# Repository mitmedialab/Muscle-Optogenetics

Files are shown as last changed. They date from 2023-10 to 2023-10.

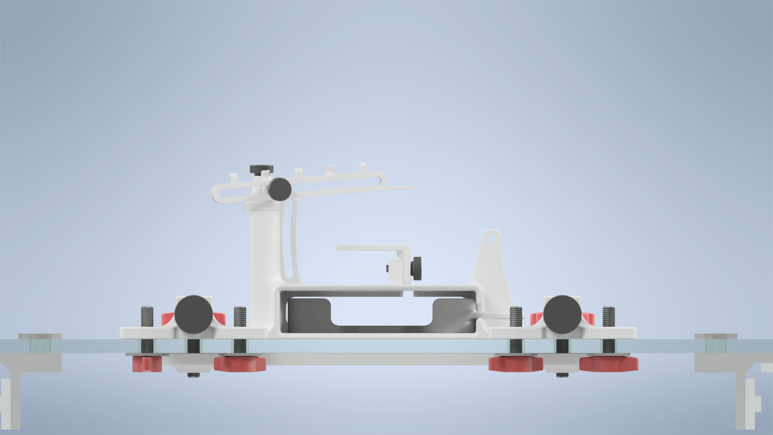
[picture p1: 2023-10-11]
Muscle Characterization Apparatus/Renders/Rendering IV.png

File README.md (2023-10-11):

# Muscle-Optogenetics

Muscle characterization apparatus and closed-loop control files for the paper: Closed-loop optogenetic neuromodulation enables high-fidelity fatigue-resistant muscle control



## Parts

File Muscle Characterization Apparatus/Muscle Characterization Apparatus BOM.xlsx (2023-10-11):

Muscle Characterization Platform Bill of Materials
Description | Use | Part no. | Supplier | Quantity | Cost | Total Cost | Notes
Stainless Steel M5 Nuts (pack of 100) | Nuts for trim adjustment hardware | 91828A241 | Mcmaster Carr (https://www.mcmaster.com/91828A241) | 1 | $5.55 | $5.55 | Just need 10 for assembly
Stainless Steel M3 Nuts (pack of 100) | Nuts for leg shelf | 91828A211 | Mcmaster Carr (https://www.mcmaster.com/91828A211) | 1 | $5.55 | $5.55 | Just need 3 for assembly
Stainless Steel 1/4"-20 Hex Nuts (pack of 50) | Nuts to bolt T-slot sliders | 92673A113 | Mcmaster Carr (https://www.mcmaster.com/92673A113) | 1 | $2.27 | $2.27 | Just need 8 for assembly
Stainless Steel M5 Fender Washers (pack of 100) | Washers to accommodate for M5 hole tolerances | 90313A103 | Mcmaster Carr (https://www.mcmaster.com/90313A103) | 1 | $5.96 | $5.96 | Just need 4 for assembly
Stainless Steel 1/4" Fender Washers (pack of 25) | Washers to accommodate for 1/4"-20 hole tolerances | 91525A415 | Mcmaster Carr (https://www.mcmaster.com/91525A415) | 1 | $8.80 | $8.80 | Just need 8 for assembly
Stainless Steel 1/4"-20 x 1" Screws (pack of 10) | Screws to bolt T-slot sliders | 92185A42 | Mcmaster Carr (https://www.mcmaster.com/92185A542) | 1 | $3.44 | $3.44 | Need 8 for assembly
Stainless Steel M5x35mm Screws (pack of 25) | Screws for trim hardware | 91292A193 | Mcmaster Carr (https://www.mcmaster.com/91292A193) | 1 | $6.07 | $6.07 | Just need 2 for assembly
Stainless Steel M5x20mm Screws (pack of 50) | Screws to clamp printed parts | 90348A022 | Mcmaster Carr (https://www.mcmaster.com/90348A022) | 1 | $9.91 | $9.91 | Need 8 for assembly
Plastic M3x10mm Thumb Screws (pack of 10) | Thumbscrew for leg shelf | 96016A553 | Mcmaster Carr (https://www.mcmaster.com/96016A553) | 1 | $5.25 | $5.25 | Just need 1
Plastic M3x20mm Thumb Screws (pack of 10) | Thumbscrews for LED Arm | 96016A556 | Mcmaster Carr (https://www.mcmaster.com/96016A556) | 1 | $5.50 | $5.50 | Just need 2
Compression Springs (pack of 5) | Springs to preload trim adjustment | 9434K58 | Mcmaster Carr (https://www.mcmaster.com/9434K58) | 1 | $4.98 | $4.98 | Just need 2 for assembly
T-Slot Frame Sliders | Sliders to adjust fixture location on T-slot frames | 47065T959 | Mcmaster Carr (https://www.mcmaster.com/47065T959) | 2 | $46.16 | $92.32 | Should have these on hand
Round M5 Thumbscrew Heads (pack of 50) | Caps to allow hand adjustments for M5 screws | 91175A063 | Mcmaster Carr (https://www.mcmaster.com/91175A063) | 1 | $10.20 | $10.20 | Just need 2--install on 35mm M5 bolts
Two Arm M5 Thumbscrew Heads (pack of 50) | Caps to allow hand adjustments for M5 screws | 91175A081 | Mcmaster Carr (https://www.mcmaster.com/91175A081) | 1 | $8.44 | $8.44 | Need 8--install on 20mm M5 bolts
Polycarbonate Baseplate | Baseplate for the fixture | W91-03630 | Curbell Plastics (https://www.curbellplastics.com/Shop-Materials/Product/Clearance-Polycarbonate-Sheet/W91-03630/Clearance-Polycarbonate-Sheet-Clear-(0-220-in-x-12-in-x-72-in)-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) | 1 | $26.50 | $26.50 | Need to cut this down to 12" by 16.5"
Stainless steel socket head M2.5 x 0.45 mm screw, 10 mm | Screw for lever transducer | 91292A014 | Mcmaster Carr (https://www.mcmaster.com/catalog/126/3304) | 1 | $5.42 | $5.42 | Just need 1
Stainless steel socket head M2.6 x 0.45 mm screw, 10 mm | Screw for lever transducer | 91292A342 | Mcmaster Carr (https://www.mcmaster.com/catalog/126/3304) | 1 | $8.58 | $8.58 | Just need 1
3D Printed Parts
Name | Use | Quantity
Long Bottom Nut Traps | Hold M5 Nuts in place for clamp hardware | 2
Fixture Pull Bracket | Trim tension bracket | 2
reviii Fixture Body | Mouse fixture | 1
Leg Shelf | Platform for mouse leg | 1
Heatpad Tray | Tray for heatpad to warm mouse | 1
LED Arm | Arm to hold UV LED | 1
LED Elbow | Joint between LED Arm and Fixture base | 1
LED Washer | Slot Washer for LED Arm | 1

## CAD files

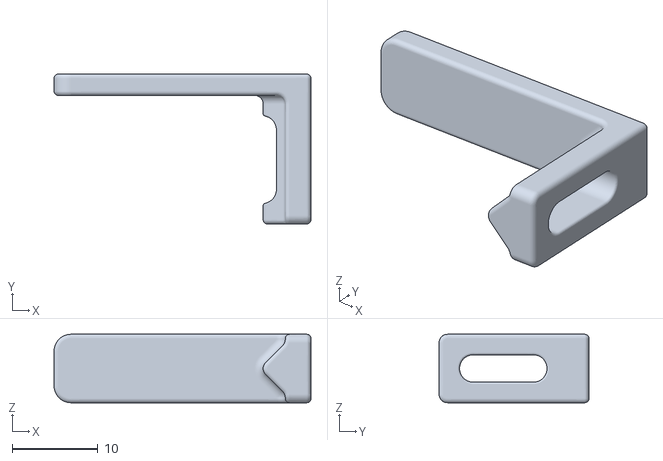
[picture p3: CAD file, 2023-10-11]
Muscle Characterization Apparatus/STLs for 3D printed parts/Leg Shelf.stl
30.0 x 17.5 x 8.00

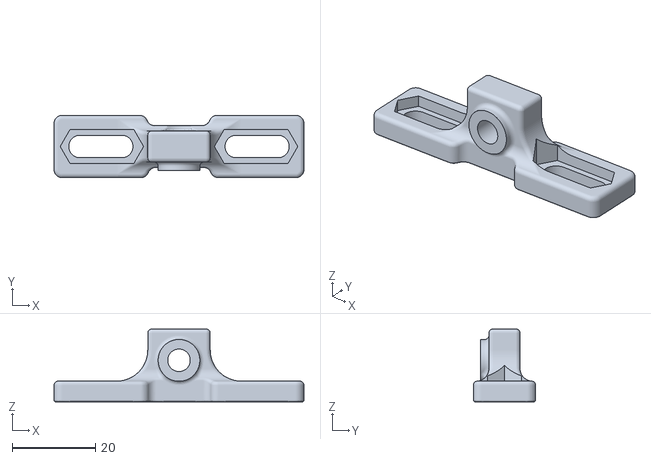
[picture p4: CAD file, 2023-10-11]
Muscle Characterization Apparatus/STLs for 3D printed parts/Fixture Pull Bracket.stl
60.0 x 15.0 x 17.5

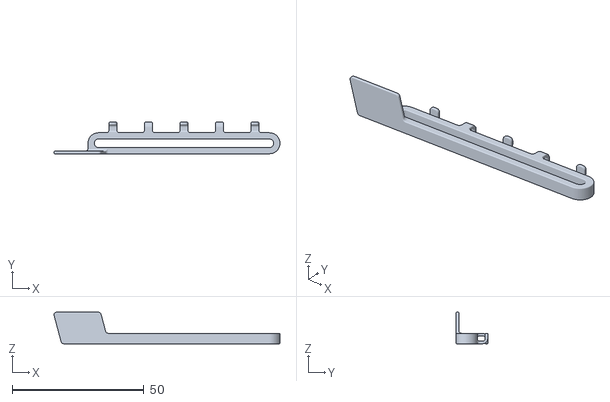
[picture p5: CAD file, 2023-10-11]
Muscle Characterization Apparatus/STLs for 3D printed parts/LED Arm.stl
85.9 x 12.0 x 12.0

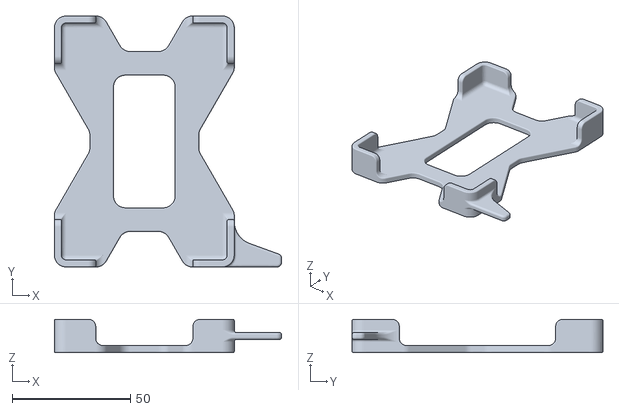
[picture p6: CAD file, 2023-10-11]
Muscle Characterization Apparatus/STLs for 3D printed parts/Heatpad Tray.stl
96.0 x 106.0 x 14.0

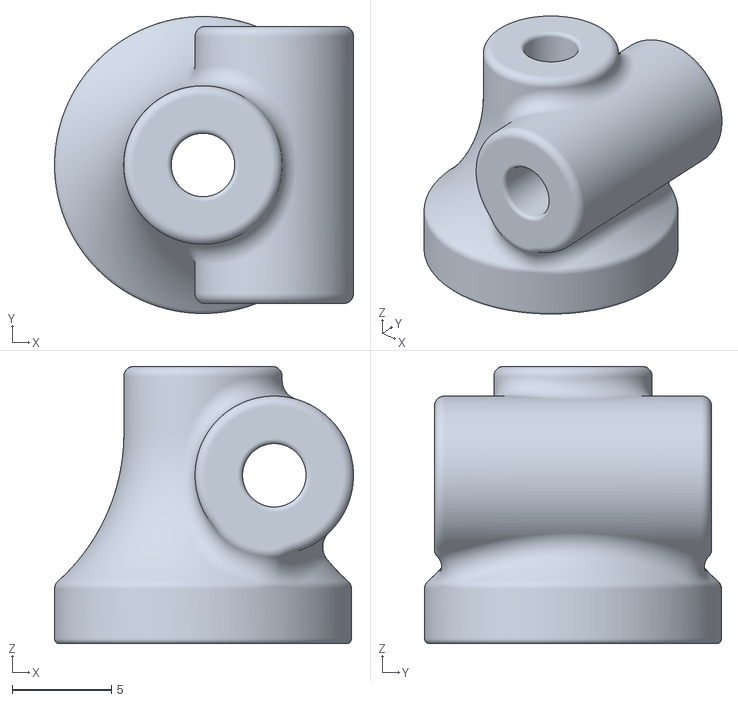
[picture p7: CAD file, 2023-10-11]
Muscle Characterization Apparatus/STLs for 3D printed parts/LED Elbow.stl
15.1 x 15.0 x 14.0

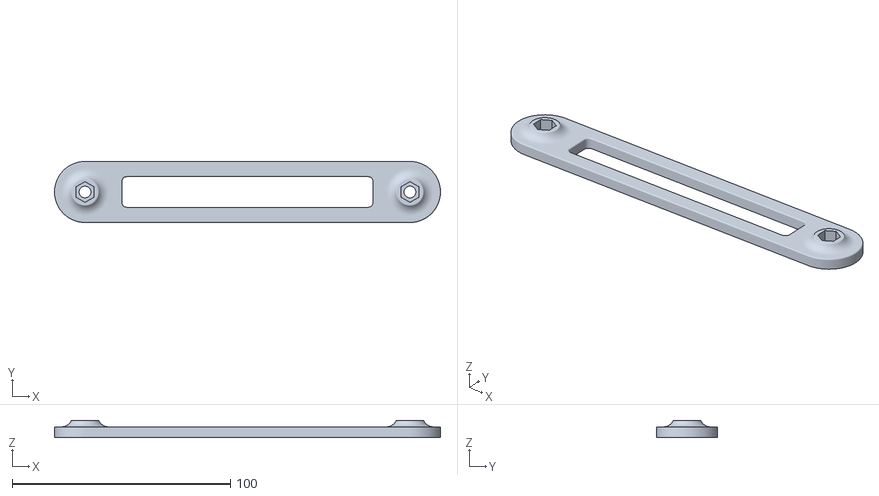
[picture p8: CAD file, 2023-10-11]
Muscle Characterization Apparatus/STLs for 3D printed parts/Long Bottom Nut Traps.stl
177.0 x 28.0 x 8.00

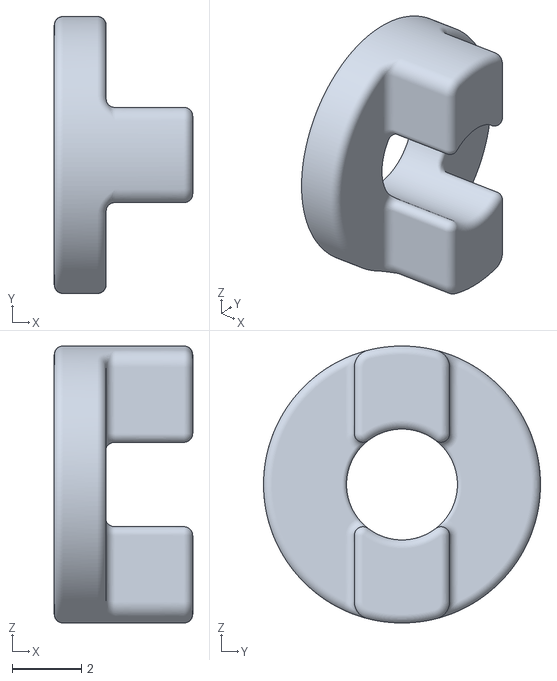
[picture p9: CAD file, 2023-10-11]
Muscle Characterization Apparatus/STLs for 3D printed parts/LED Washer.stl
4.00 x 8.00 x 8.00

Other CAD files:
Muscle Characterization Apparatus/Inventor Files - rev ix/47065T959_ALUMINUM T-SLOTTED FRAMING EXTRUSION.ipt
Muscle Characterization Apparatus/Inventor Files - rev ix/90313A103_18-8 STAINLESS STEEL OVERSIZED WASHER.ipt
Muscle Characterization Apparatus/Inventor Files - rev ix/91525A415_TYPE 316 STAINLESS STEEL FLAT WASHER.ipt
Muscle Characterization Apparatus/Inventor Files - rev ix/9434K580_MUSIC-WIRE STEEL COMPRESSION SPRINGS.ipt
Muscle Characterization Apparatus/Inventor Files - rev ix/Base Plate.ipt
Muscle Characterization Apparatus/Inventor Files - rev ix/Fixture Pull Bracket.ipt
Muscle Characterization Apparatus/Inventor Files - rev ix/Heatpad Tray.ipt
Muscle Characterization Apparatus/Inventor Files - rev ix/LED Arm.ipt
Muscle Characterization Apparatus/Inventor Files - rev ix/LED Elbow.ipt
Muscle Characterization Apparatus/Inventor Files - rev ix/LED Washer.ipt
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

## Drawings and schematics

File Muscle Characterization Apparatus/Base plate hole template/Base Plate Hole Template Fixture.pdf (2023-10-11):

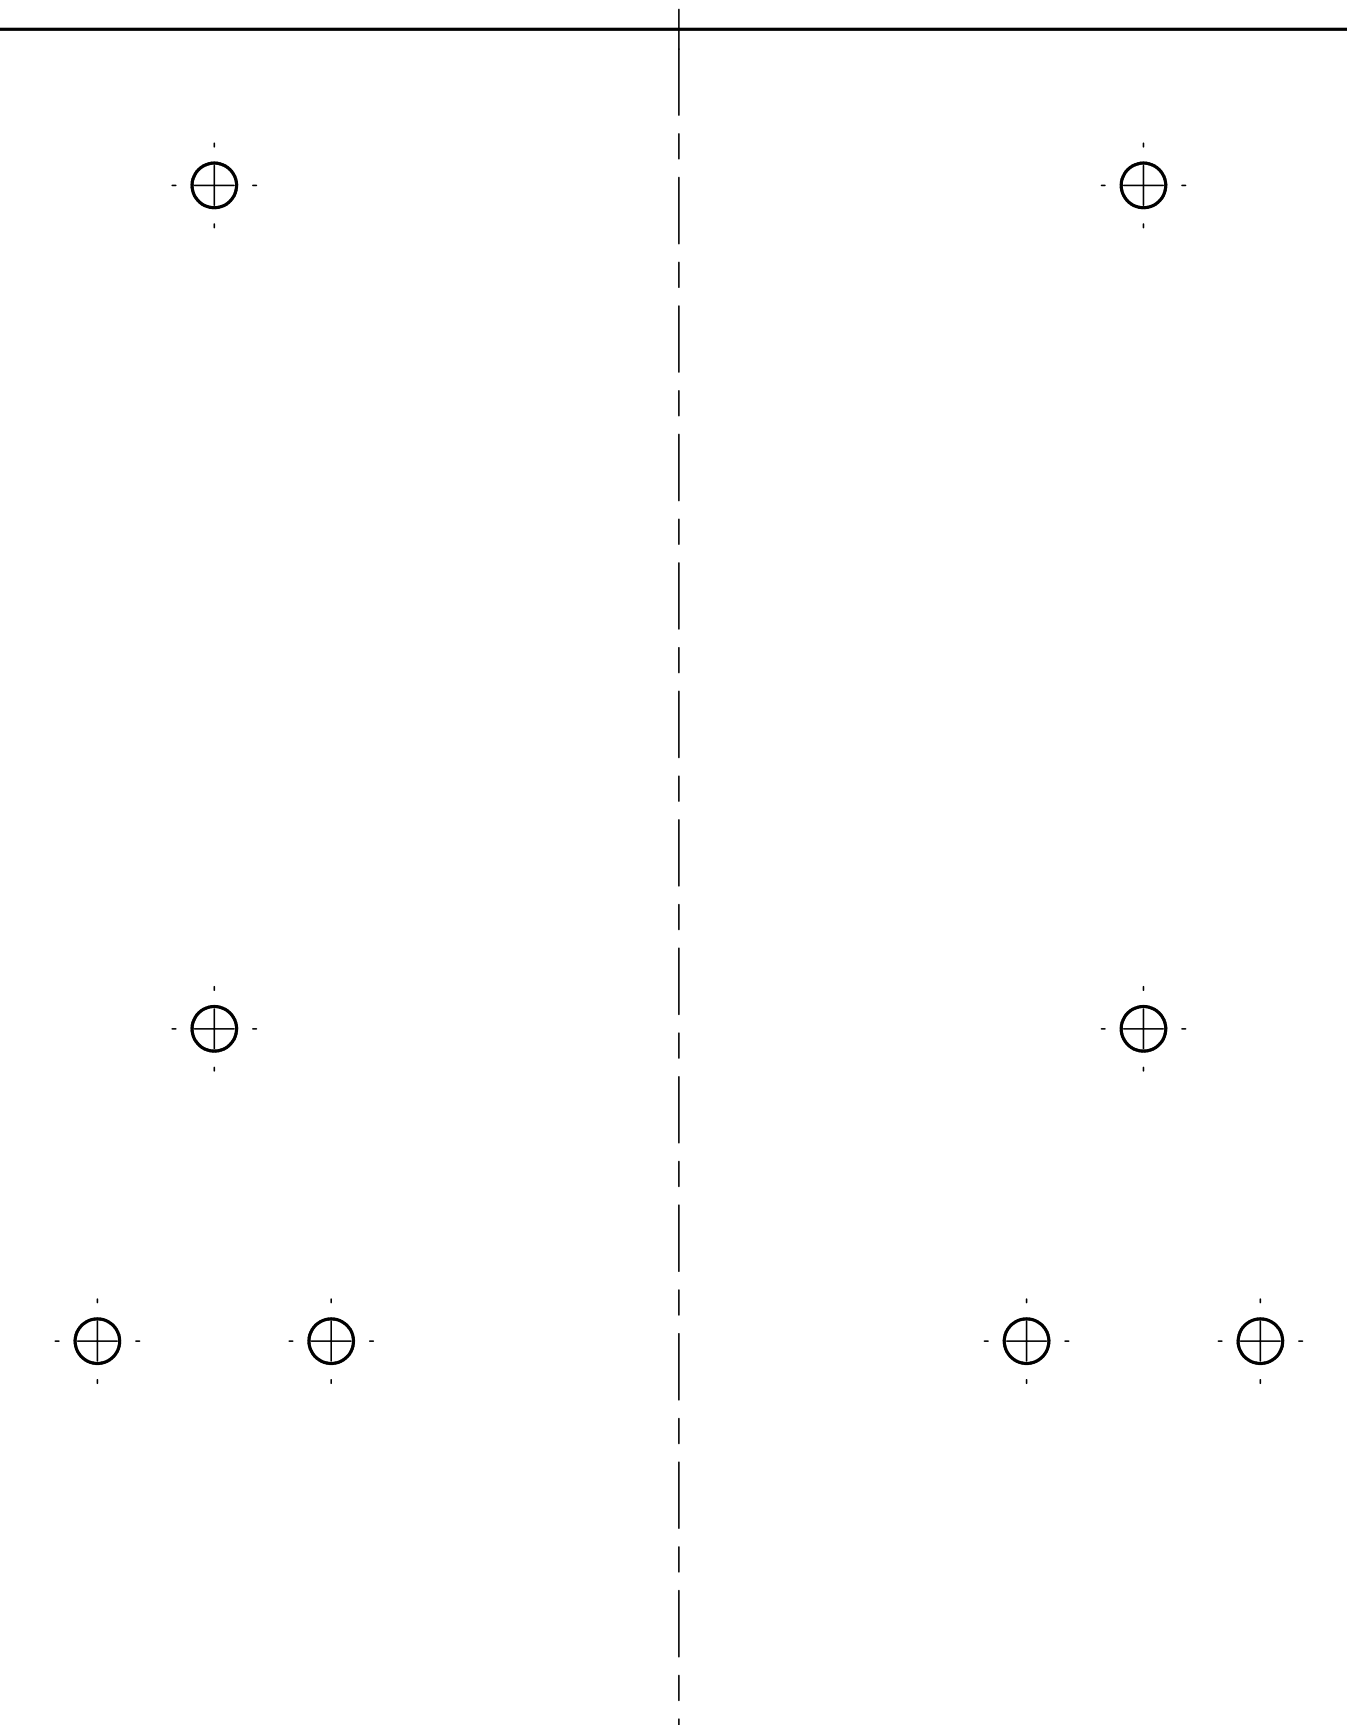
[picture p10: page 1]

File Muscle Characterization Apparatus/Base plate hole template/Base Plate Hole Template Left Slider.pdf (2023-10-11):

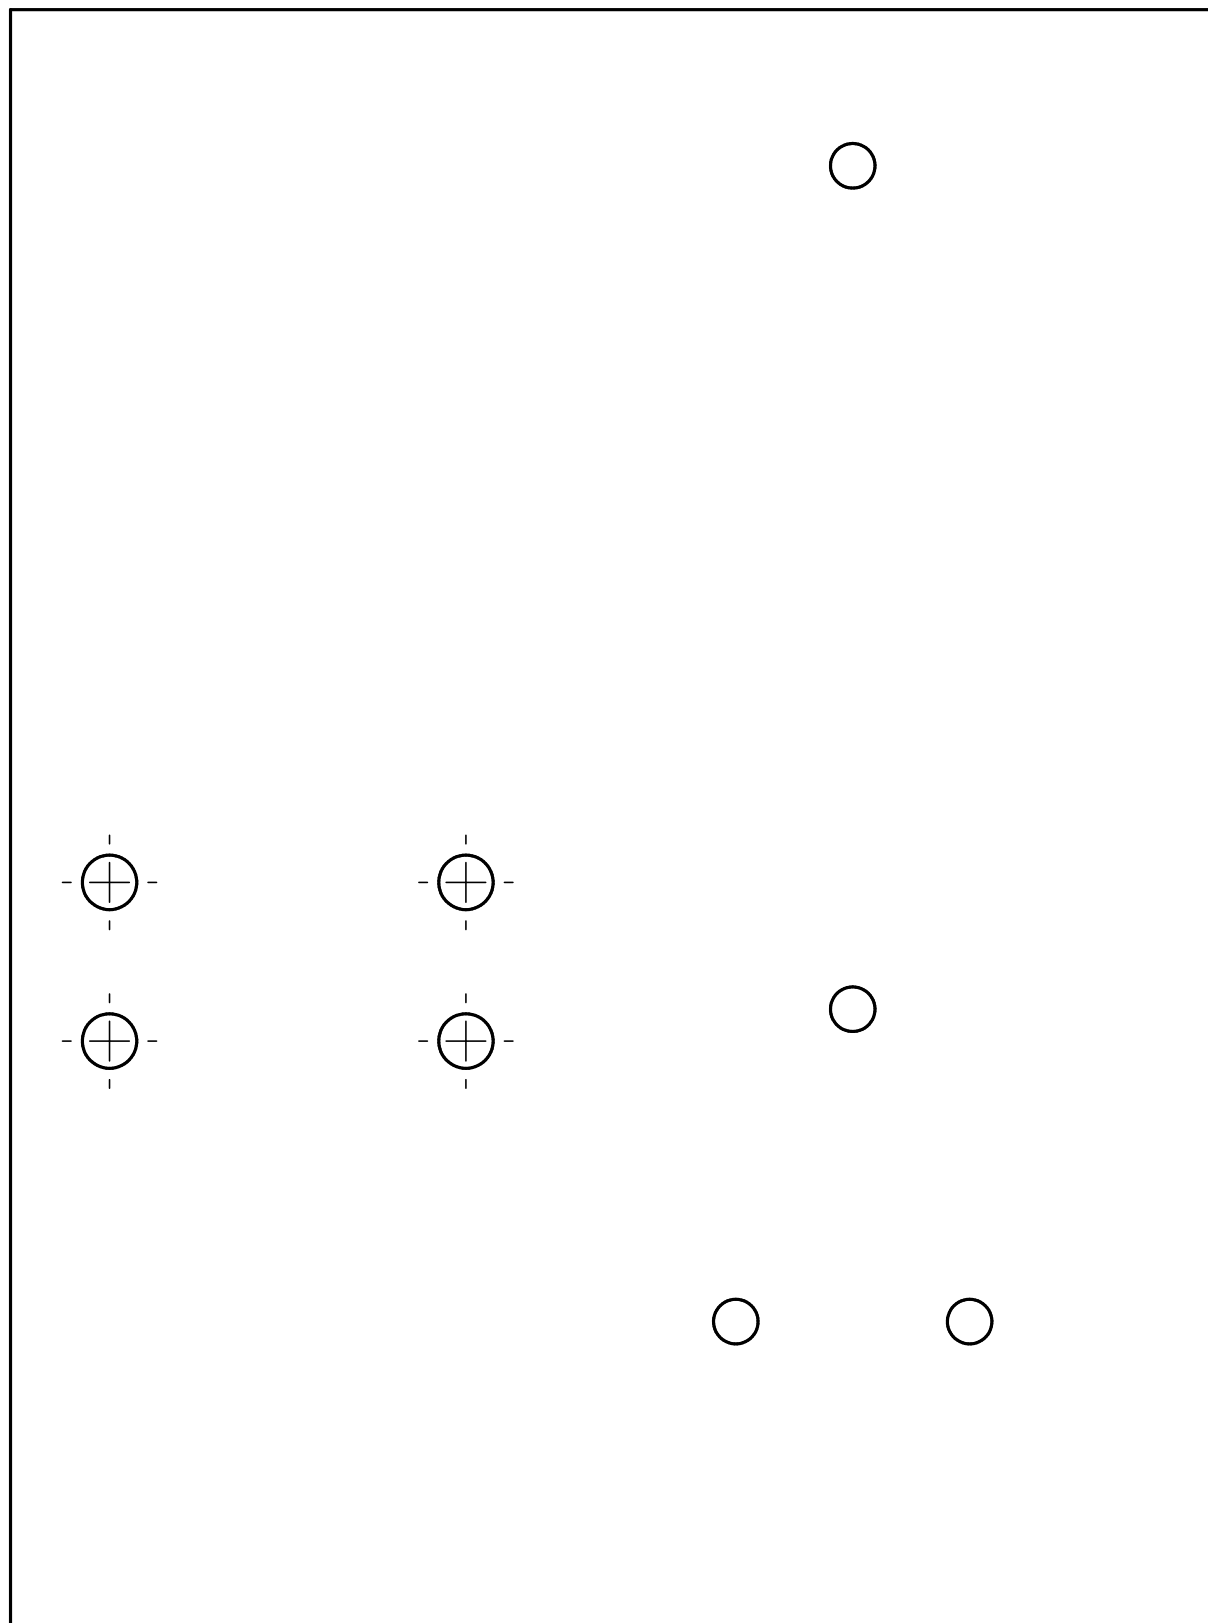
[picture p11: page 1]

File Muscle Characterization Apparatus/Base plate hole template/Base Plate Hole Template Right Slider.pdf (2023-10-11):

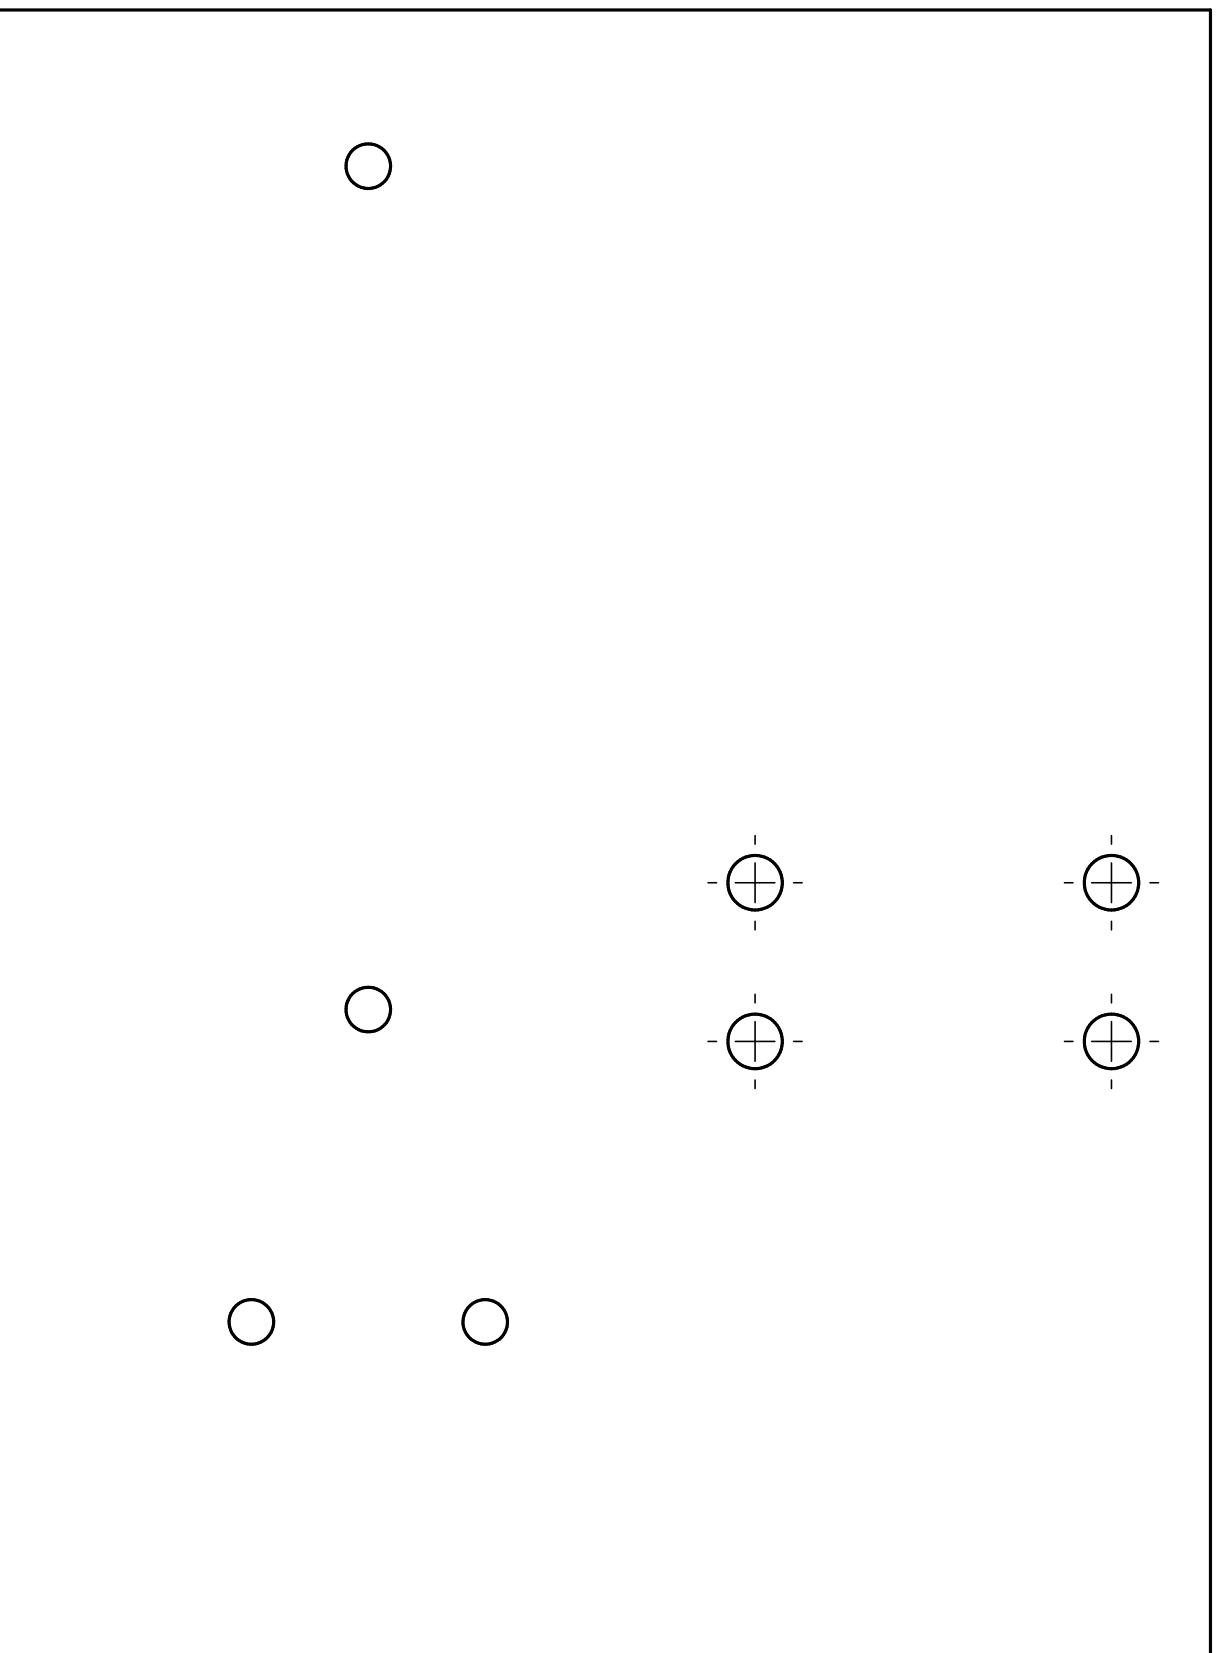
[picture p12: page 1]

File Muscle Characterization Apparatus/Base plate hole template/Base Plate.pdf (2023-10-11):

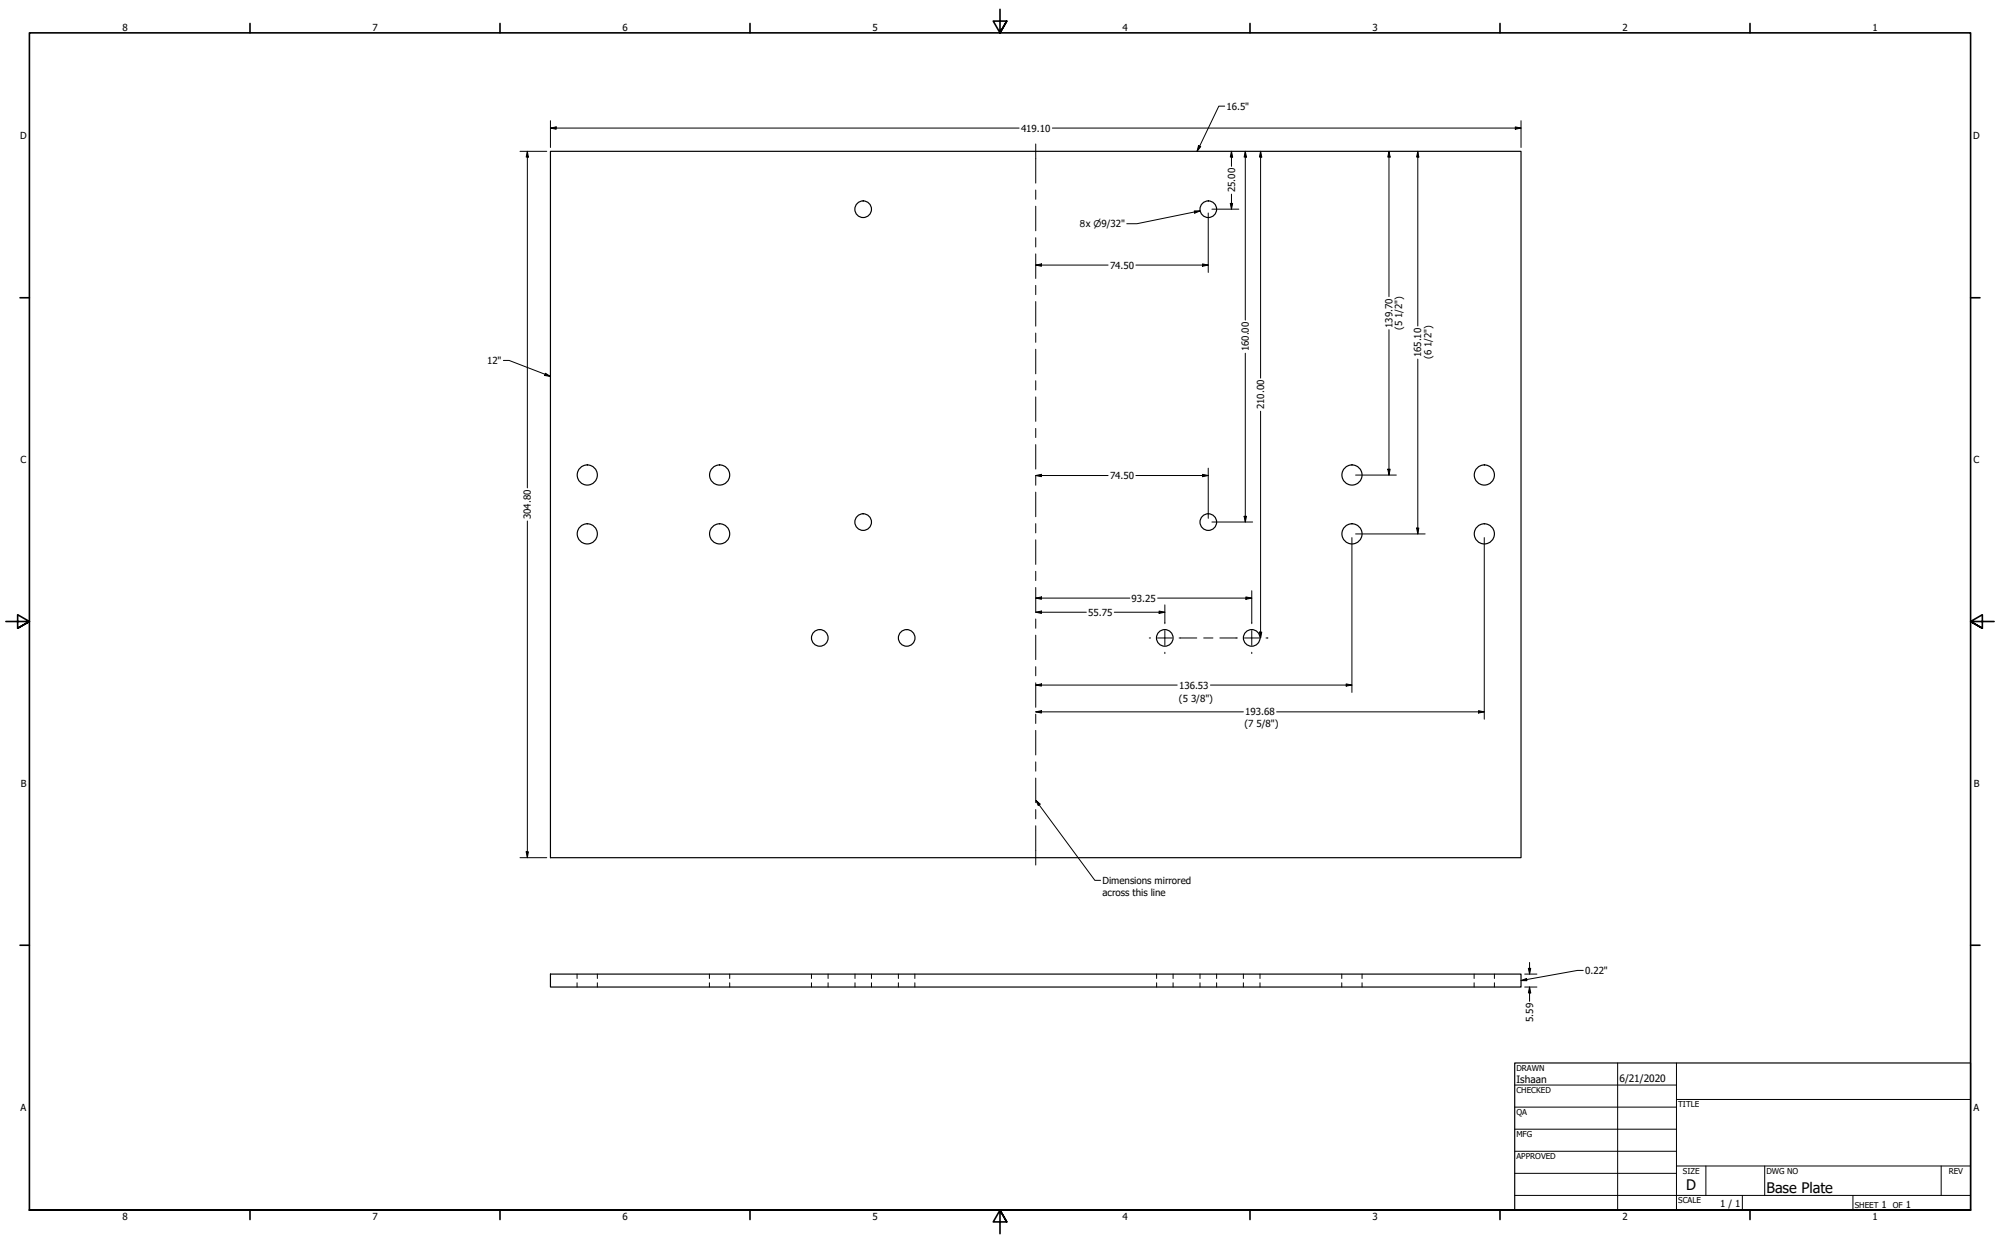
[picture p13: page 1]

S I Z E D | D W G N O B a s e Pla t e | R E V
